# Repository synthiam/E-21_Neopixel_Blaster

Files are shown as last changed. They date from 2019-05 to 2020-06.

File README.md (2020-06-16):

# E-21 Neopixel Blaster

**Project Status:** Ready to manufacture

If you are new to GitHub and would like to create a derivative of this project, please have a look at GitHub instructions to [fork a repo](https://help.github.com/en/articles/fork-a-repo)

## Description

Out of our passion to solve the issue of time waste in the robot creation process, ARC was born. The ARC software platform reduces the time it takes to get from idea to implementation. Since 2011 we have been listening to the challenges robot builders encounter and continue to provide them with an ever expanding toolbox of solutions. Join us on this journey!

We didn't stop at the software, we also made time saving hardware solutions. This Neopixel Blaster reference design is one of them. The Neopixel blaster connects WS2812 Addressable RGB LEDs to ARC. By utilizing ARC, the Neopixel Blaster can create animations and display all kinds of colors with WS2812B LEDs. A unique feature of this board is that it allows any EZ-Builder compatible board to use Neopixel LEDs, no libraries or precision timing required. We want to share these files with you so you can create your own version for your community and customers to enjoy!

**Features:** 
- 8 channels 
- Control up to 80 LEDs per channel
- Each LED can display 1 of 16 million different colors
- Mini programming header
- 5V tolerant I/O pins
- RGB LED status indicator
- ARC skill available
- Voltage requirement: 6-18VDC (7.4V Typical)
- Current draw: WS2812B off - 7mA, WS2812B white - 46mA
- Dimensions: 29.7(W) x 35.7(L) x 11.5(H) (mm)
- Weight: 5g

**Major components:** 
- PIC16F1704-I/ST 8-bit PIC microcontroller (custom firmware provided)
- NCP1117ST50T3GOSCT 5V Linear voltage regulator
- WS2812B Addressable RGB LED

**Manufacturing notes:** 
1. Supplier: programs custom firmware into the PIC16F1704-I/ST at their facility before sending to manufacturer
2. Manufacturer: Single side placement and soldering of SMT components
3. Manufacturer: Single Side soldering of THT components

**Note:** This reference design pairs with either a WS2812B NeoPixel LED or a Blaster Bit from here: https://github.com/synthiam/E-22_Blaster_Bit

## Contents

[**Documentation:**](https://github.com/synthiam/E-21_Neopixel_Blaster/tree/master/E-21%20Documentation) Schematic PDF, Datasheet PDF, BOM, Test Procedures

[**Hardware:**](https://github.com/synthiam/E-21_Neopixel_Blaster/tree/master/E-21%20Hardware) Altium PCB design File, Altium SCH Design File, Gerbers

[**Firmware:**](https://github.com/synthiam/E-21_Neopixel_Blaster/tree/master/E-21%20Firmware) Code, Compiled Hex

*Altium Libraries are also available <a href="https://github.com/synthiam/Synthiam_Altium_Librairies">here</a>*

## Photos

<p align="left">


</p>

## Roll Out Video

This Roll-out Video includes:

1. Feature set 
2. Hook-up guide 
3. Using Synthiam EZ-Builder Software Behavior Control
4. Custom firmware location
5. Schematic overview
6. Bill of Materials (BOM) overview
7. Assembly instructions 

Link: https://youtu.be/iWZ4e5sMYgQ



## ARC Skill

The ARC Neopixel Blaster skill makes it easy to control the Neopixel LEDs. The LED colors can be chained and activated with a simple code segment. 

Link: https://synthiam.com/Software/Manual/Neopixel-Blaster-16172



## Contact

For profit use of these files requires written consent. Contact partners@synthiam.com. For everyone else, party on!

For support check out our Synthiam Community: https://synthiam.com/Community

## License

This project is released under the following licenses:

**Hardware:** Creative Commons Plus Attribution-NonCommercial 4.0 International (CC+ BY-NC 4.0)

**Firmware:** Apache 2.0 + “Commons Clause” License Condition v1.0

Please see [LICENSE.md](https://github.com/synthiam/E-21_Neopixel_Blaster/blob/master/LICENSE.md) for license details.



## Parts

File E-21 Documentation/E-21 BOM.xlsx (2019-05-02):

Qty | Description | Manufacturer Part No. | Alternative | Designator | Custom Information | Link
E-21 Neopixel Blaster
1 | 2 layer, Blue soldermask, White silkscreen, ENIG | Neopixel Blaster Board |  | PCB
1 | MicroChip PIC microcontroller | PIC16F1704-I/ST |  | U1 | Needs custom Firmware programmed into chip | https://www.digikey.ca/products/en?keywords=PIC16F1704-I%2FST
1 | 5V Linear voltage regulator (1A) upto 18V | NCP1117ST50T3GOSCT |  | VR1 |  | https://www.digikey.ca/products/en?keywords=NCP1117ST50T3GOSCT
2 | 0.1uF 16V 0805 Ceramic Capacitor | CL21F104ZBCNNNC | C0805C104K5RAC | C3, C4
2 | 10uF 25V 0805 Ceramic Capacitor | CL21A106KAFN3NE |  | C1, C2
1 | 4.7kohm 0805 Chip resistor | RR1220P-472-D |  | R1
1 | 40-pin White Male 0.1" pitch Header |  |  | P7, P10 | This header needs to be broken down into 2 x 4-pin | https://www.adafruit.com/product/4149
1 | 40-pin Red Male 0.1" pitch Header | FIT0084-R |  | P8, P11 | This header needs to be broken down into 2 x 4-pin | https://www.dfrobot.com/product-650.html#.Ulc-U1CshcZ
1 | 40-pin Black Male 0.1” pitch header | FIT0084-B | 00834 | P9, P12 | This header needs to be broken down into 2 x 4-pin | http://www.4uconnector.com/online/SearchPro.asp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
1 | Addressable RGB LED | WS2812B |  | U2 |  | https://www.alibaba.com/product-detail/SK6812B-WS2812B-5050-RGB-Packing-LED_60329442470.html
1 | 3 position 2.0mm pitch JST-PH header | B3B-PH-K-S(LF)(SN) |  | P2 |  | https://www.digikey.ca/product-detail/en/jst-sales-america-inc/B3B-PH-K-S-LF-SN/455-1705-ND/926612

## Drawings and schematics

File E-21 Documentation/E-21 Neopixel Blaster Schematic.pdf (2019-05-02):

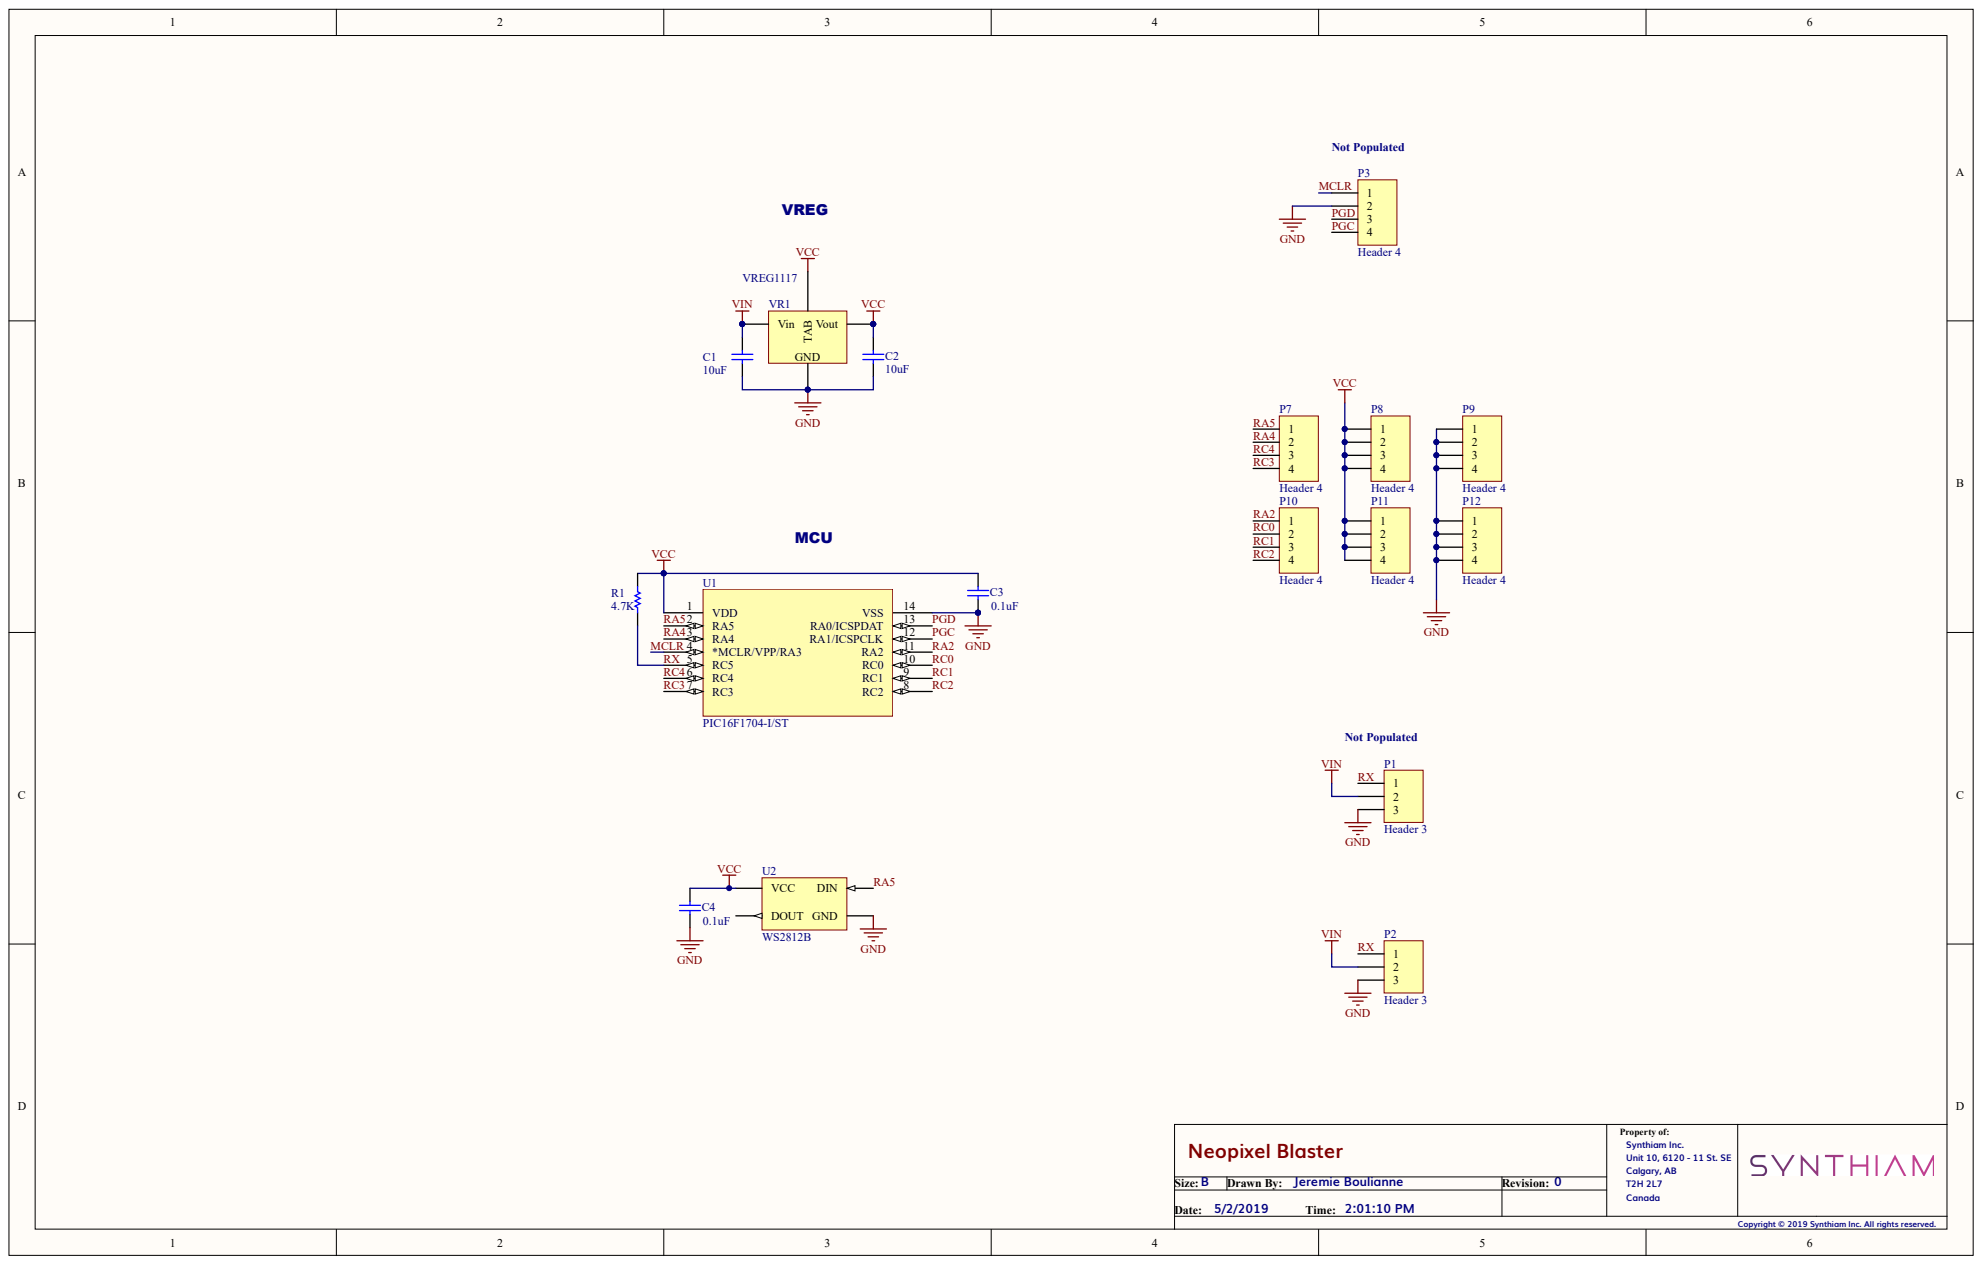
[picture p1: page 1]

Neopixel Blaster | Property of: Synthiam Inc. Unit 10, 6120 - 11 St. SE Calgary, AB T2H 2L7 Canada

B Size: | Jeremie Boulianne Drawn By: | 0 Revision:
5/2/2019 2:01:10 PM Date: Time:

Copyright © 2019 Synthiam Inc. All rights reserved.

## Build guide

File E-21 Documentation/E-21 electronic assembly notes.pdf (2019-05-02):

# Assembly Instructions

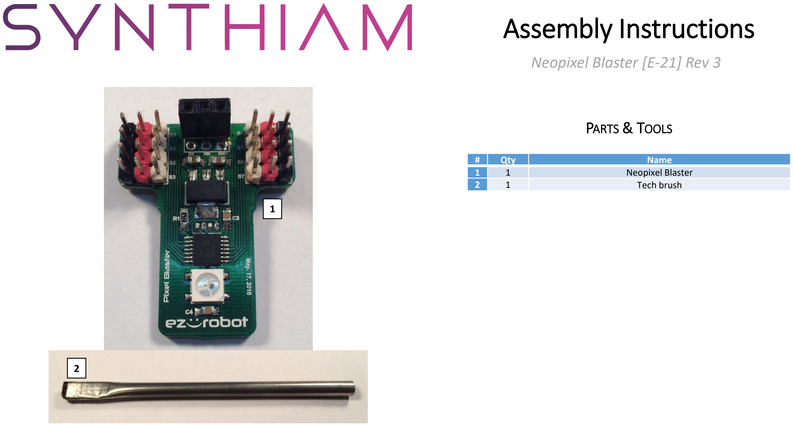
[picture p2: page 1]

# | Qty | Name

1 | 1 | Neopixel Blaster
2 | 1 | Tech brush

Neopixel Blaster [E-21] Rev 3

PARTS & TOOLS

1

2

U1

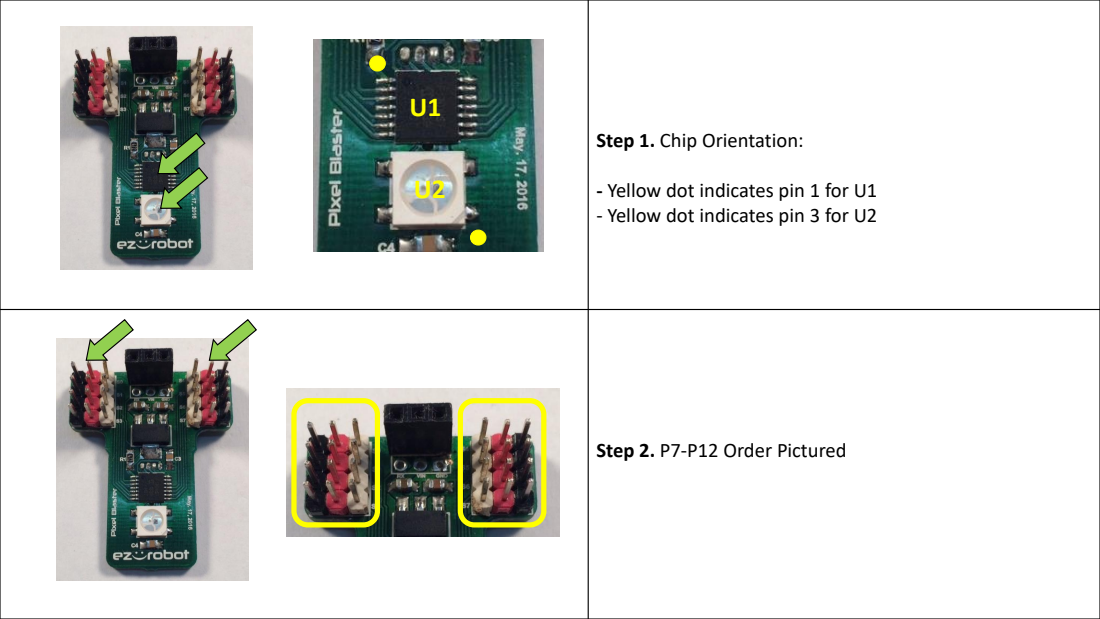
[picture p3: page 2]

Step 1. Chip Orientation:

- Yellow dot indicates pin 1 for U1
- Yellow dot indicates pin 3 for U2

Step 2. P7-P12 Order Pictured

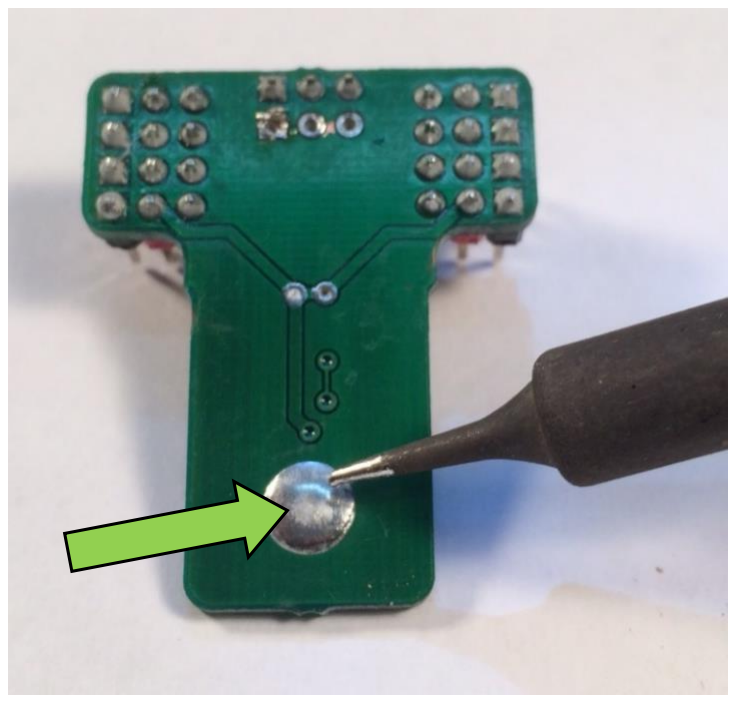
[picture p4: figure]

Step 3. Solder a ~0.020” high circular blob on area pictured

*IMPORTANT*
This is step is imperative for precision fit with ez-clip slots.

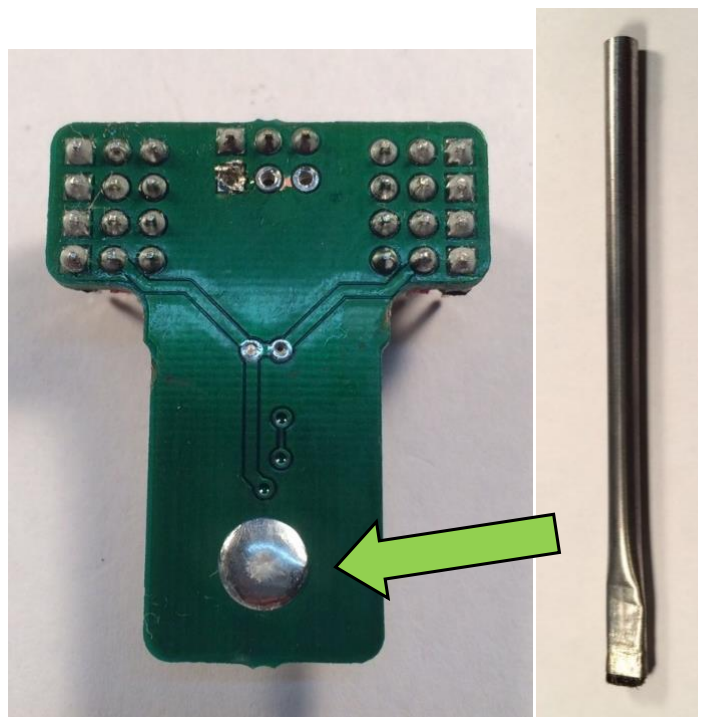
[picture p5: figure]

Step 4. Clean the flux of the PCB with a tech brush

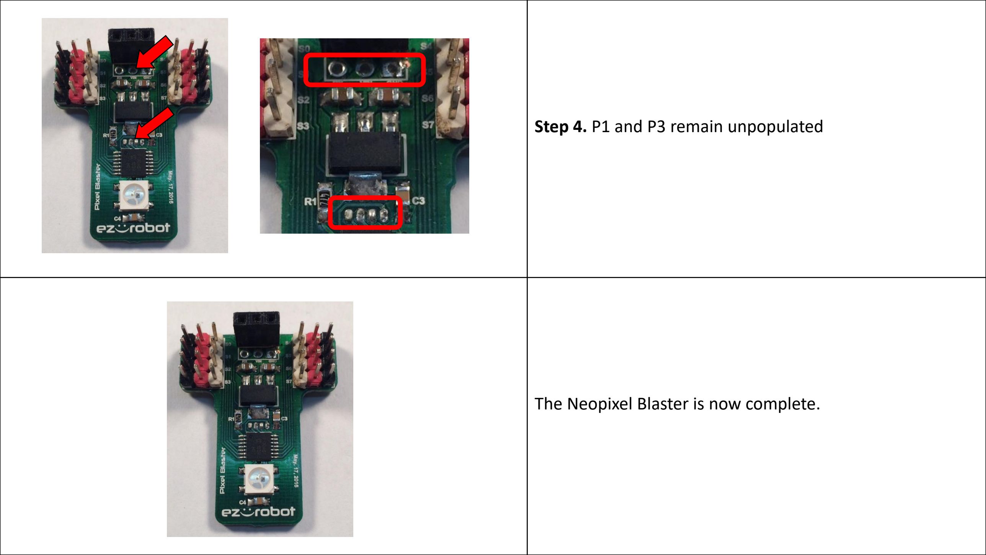
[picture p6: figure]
The Neopixel Blaster is now complete.

Step 4. P1 and P3 remain unpopulatedrush

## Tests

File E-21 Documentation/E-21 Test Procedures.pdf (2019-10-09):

# E-21 Test Procedures

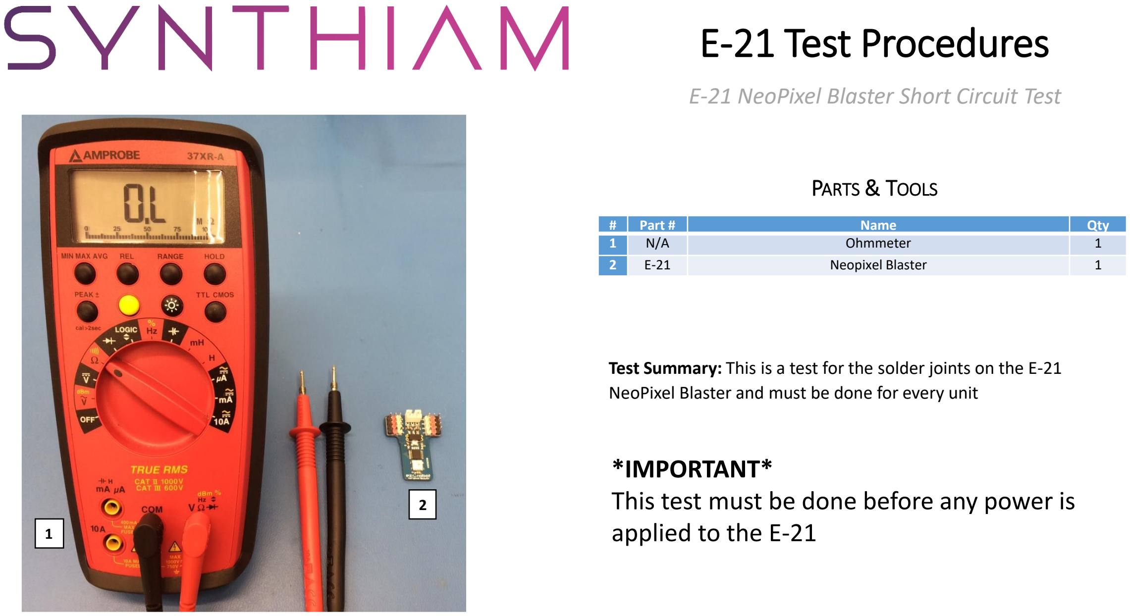
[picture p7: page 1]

# | Part # | Name | Qty

1 | N/A | Ohmmeter | 1
2 | E-21 | Neopixel Blaster | 1

E-21 NeoPixel Blaster Short Circuit Test

PARTS & TOOLS

Test Summary: This is a test for the solder joints on the E-21 NeoPixel Blaster and must be done for every unit

*IMPORTANT*
This test must be done before any power is

### 1 applied to the E-21

2

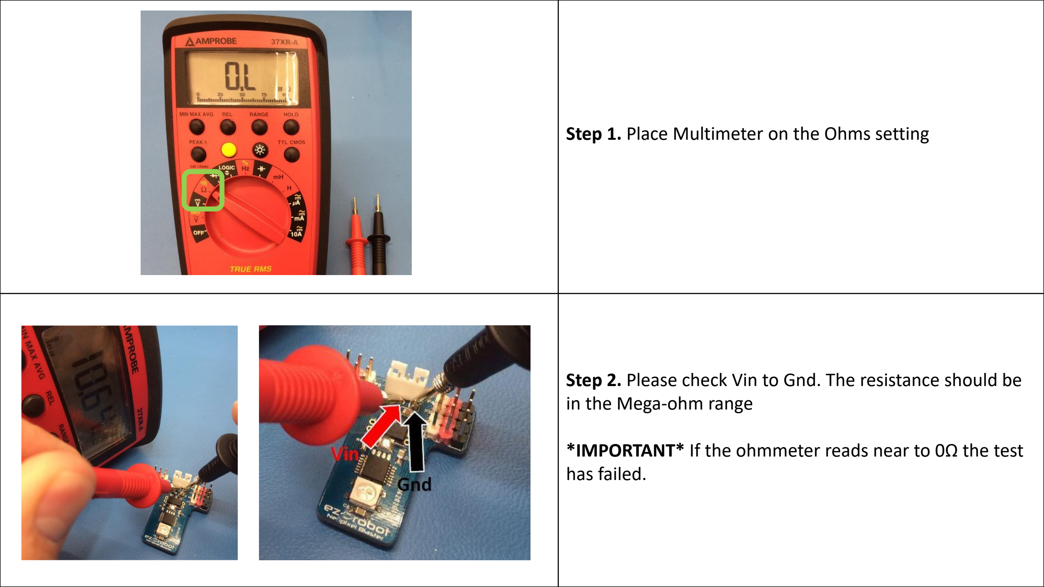
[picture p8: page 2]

Step 1. Place Multimeter on the Ohms setting
Step 2. Please check Vin to Gnd. The resistance should be in the Mega-ohm range

*IMPORTANT* If the ohmmeter reads near to 0Ω the test has failed.

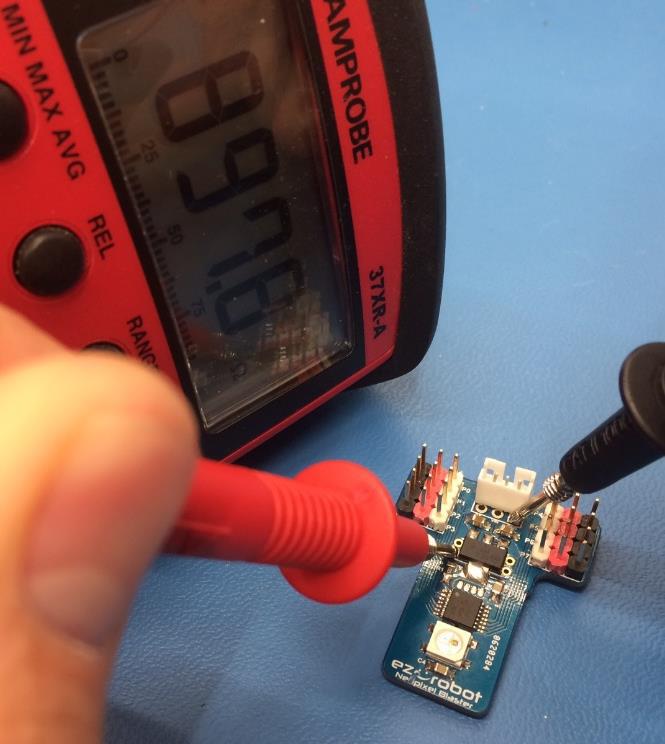
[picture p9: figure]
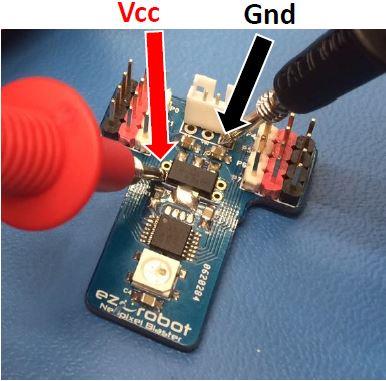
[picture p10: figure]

Step 3. Please check Vcc to Gnd. The resistance should be over 800ohms. The E-21 Short Circuit Test is now complete

*IMPORTANT* If the ohmmeter reads near to 0Ω the test has failed.

# E-21 Test Procedures

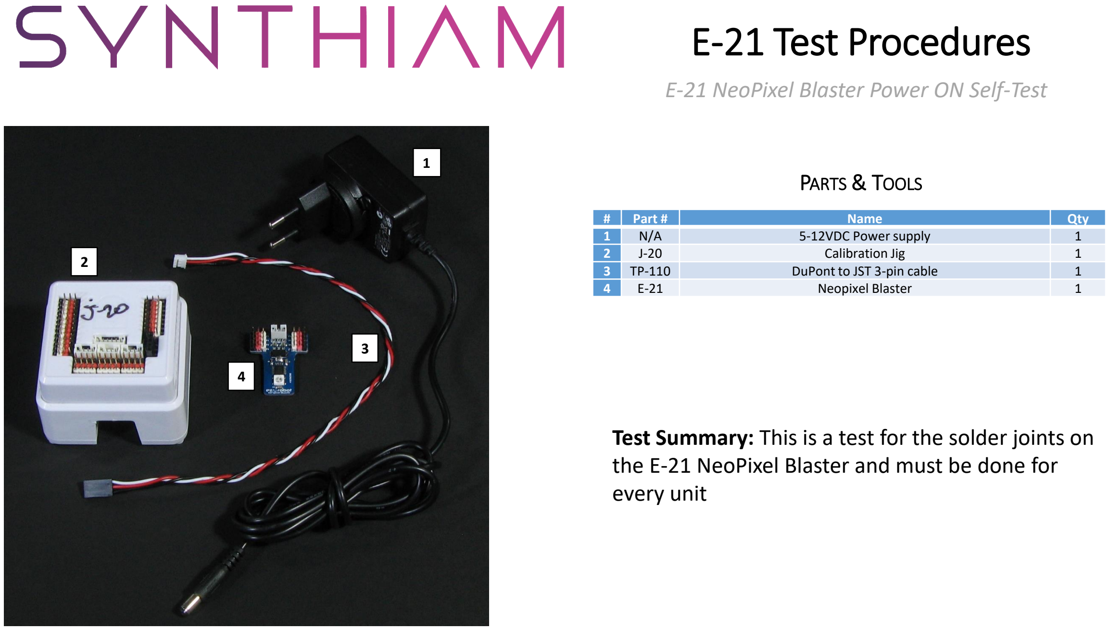
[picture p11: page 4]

# | Part # | Name | Qty

1 | N/A | 5-12VDC Power supply | 1
2 | J-20 | Calibration Jig | 1
3 | TP-110 | DuPont to JST 3-pin cable | 1
4 | E-21 | Neopixel Blaster | 1

E-21 NeoPixel Blaster Power ON Self-Test

PARTS & TOOLS

1

2

3

4

Test Summary: This is a test for the solder joints on the E-21 NeoPixel Blaster and must be done for every unit

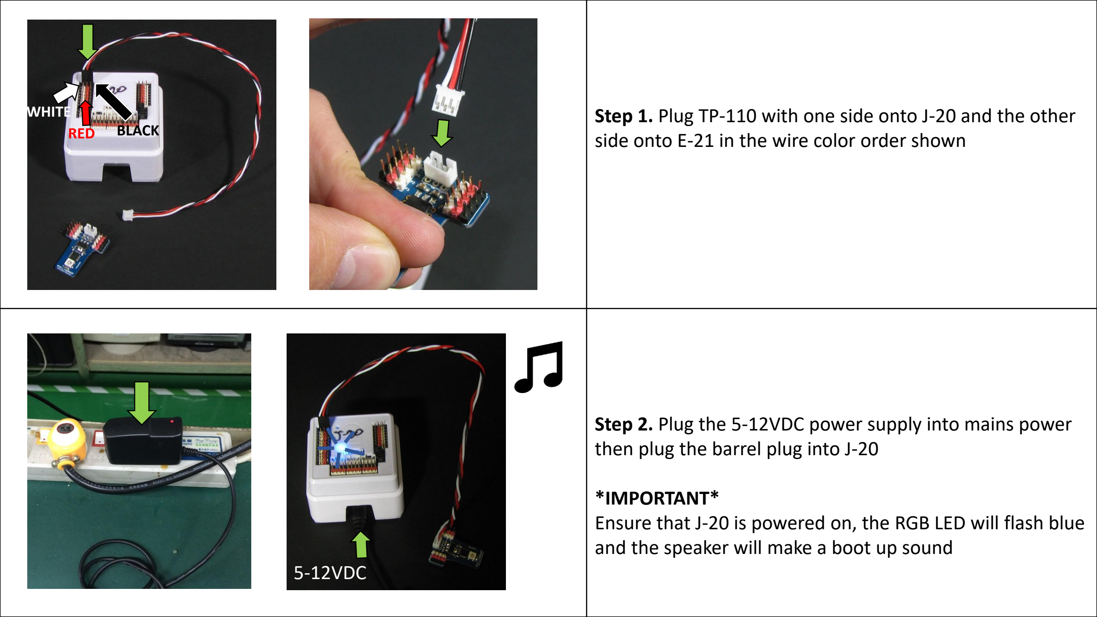
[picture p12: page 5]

Step 1. Plug TP-110 with one side onto J-20 and the other side onto E-21 in the wire color order shown
Step 2. Plug the 5-12VDC power supply into mains power then plug the barrel plug into J-20

*IMPORTANT*
Ensure that J-20 is powered on, the RGB LED will flash blue and the speaker will make a boot up sound

WHITE
RED BLACK

5-12VDC

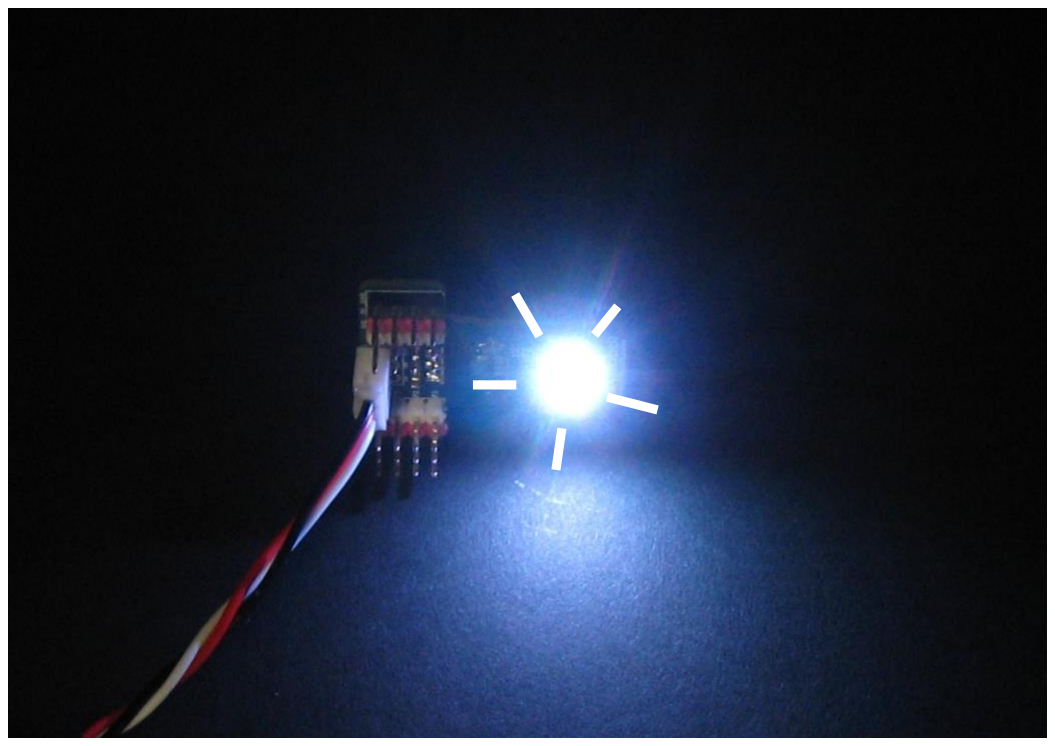
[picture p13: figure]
5-12VDC

Step 3. The LED on E-21 should now flash white very quickly and then turn off

*IMPORTANT* If the LED does not flash E-21 has failed the Power ON test

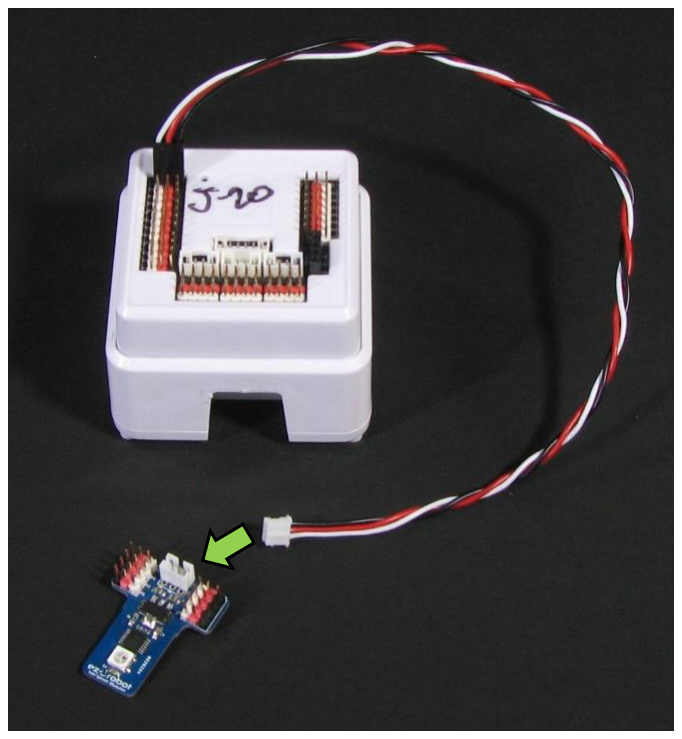
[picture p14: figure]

Step 4. Remove E-21 from TP-110. The E-21 Power ON Self-Test is now complete

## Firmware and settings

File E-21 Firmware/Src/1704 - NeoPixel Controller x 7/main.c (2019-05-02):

#include <main.h>

volatile char _buffer[240];     // This buffer is used to transmit to the neo pixels. support for 80 neopixels per channel
volatile char _outputPort;
volatile char _bufferSize;

volatile char _bufferRecv[240]; // This buffer is used in the receive from the COMM. support for 80 neopixels per channel
volatile char _outputPortRecv;
volatile char _bufferSizeRecv;

volatile char _inputState; // 0 = get port, 1 = number of leds, 2 = data
volatile char _inputPosition;
volatile int1 _startSending;

#INT_RDA
void  RDA_isr(void) {
  
  switch (_inputState) {
  
    case 0:
    
      // get the port
      _outputPortRecv = getc(COMM);
           
      // next read byte is the number of leds
      _inputState = 1;
      
      break;

    case 1:
    
      // get the number of leds
      _bufferSizeRecv = getc(COMM);
            
      // multiply the number of leds by 3 to get the buffer size (for each color of red green blue)
      _bufferSizeRecv += _bufferSizeRecv + _bufferSizeRecv;
              
      // all next bytes are the data
      _inputState = 2;
      
      break;
      
    case 2:

      _bufferRecv[_inputPosition] = getc(COMM);
      
      _inputPosition++;
      
      if (_inputPosition == _bufferSizeRecv)        
        _startSending = true; // tell the main loop to start sending
      
      break;
  }  
}

#inline
void ChangeLED0() {

  for (unsigned int16 p=0; p < _bufferSize; p++) {
  
    char dataByte = _buffer[p];
    
    if (bit_test(dataByte, 7)) {
    
      output_high(pin_a5);
      delay_cycles(DELAY_HIGH_1);
      output_low(pin_a5);
//        delay_cycles(DELAY_LOW_1);
    } else {
    
      output_high(pin_a5);
      delay_cycles(DELAY_HIGH_0);
      output_low(pin_a5);
      delay_cycles(DELAY_LOW_0);
    }             
    
    if (bit_test(dataByte, 6)) {
    
      output_high(pin_a5);
      delay_cycles(DELAY_HIGH_1);
      output_low(pin_a5);
//        delay_cycles(DELAY_LOW_1);
    } else {
    
      output_high(pin_a5);
      delay_cycles(DELAY_HIGH_0);
      output_low(pin_a5);
      delay_cycles(DELAY_LOW_0);
    }             
    
    if (bit_test(dataByte, 5)) {
    
      output_high(pin_a5);
      delay_cycles(DELAY_HIGH_1);
      output_low(pin_a5);
//        delay_cycles(DELAY_LOW_1);
    } else {
    
      output_high(pin_a5);
      delay_cycles(DELAY_HIGH_0);
      output_low(pin_a5);
      delay_cycles(DELAY_LOW_0);
    }             
    
    if (bit_test(dataByte, 4)) {
    
      output_high(pin_a5);
      delay_cycles(DELAY_HIGH_1);
      output_low(pin_a5);
//        delay_cycles(DELAY_LOW_1);
    } else {
    
      output_high(pin_a5);
      delay_cycles(DELAY_HIGH_0);
      output_low(pin_a5);
      delay_cycles(DELAY_LOW_0);
    }             
    
    if (bit_test(dataByte, 3)) {
    
      output_high(pin_a5);
      delay_cycles(DELAY_HIGH_1);
      output_low(pin_a5);
//        delay_cycles(DELAY_LOW_1);
    } else {
    
      output_high(pin_a5);
      delay_cycles(DELAY_HIGH_0);
      output_low(pin_a5);
      delay_cycles(DELAY_LOW_0);
    }             
    
    if (bit_test(dataByte, 2)) {
    
      output_high(pin_a5);
      delay_cycles(DELAY_HIGH_1);
      output_low(pin_a5);
//        delay_cycles(DELAY_LOW_1);
    } else {
    
      output_high(pin_a5);
      delay_cycles(DELAY_HIGH_0);
      output_low(pin_a5);
      delay_cycles(DELAY_LOW_0);
    }             
    
    if (bit_test(dataByte, 1)) {
    
      output_high(pin_a5);
      delay_cycles(DELAY_HIGH_1);
      output_low(pin_a5);
//        delay_cycles(DELAY_LOW_1);
    } else {
    
      output_high(pin_a5);
      delay_cycles(DELAY_HIGH_0);
      output_low(pin_a5);
      delay_cycles(DELAY_LOW_0);
    }             

    if (bit_test(dataByte, 0)) {
    
      output_high(pin_a5);
      delay_cycles(DELAY_HIGH_1);
      output_low(pin_a5);
//        delay_cycles(DELAY_LOW_1);
    } else {
    
      output_high(pin_a5);
      delay_cycles(DELAY_HIGH_0);
      output_low(pin_a5);
      delay_cycles(DELAY_LOW_0);
    }             
  }
}

#inline
void ChangeLED1() {

  for (unsigned int16 p=0; p < _bufferSize; p++) {
  
    char dataByte = _buffer[p];
    
    if (bit_test(dataByte, 7)) {
    
      output_high(pin_a4);
      delay_cycles(DELAY_HIGH_1);
      output_low(pin_a4);
//        delay_cycles(DELAY_LOW_1);
    } else {
    
      output_high(pin_a4);
      delay_cycles(DELAY_HIGH_0);
      output_low(pin_a4);
      delay_cycles(DELAY_LOW_0);
    }             
    
    if (bit_test(dataByte, 6)) {
    
      output_high(pin_a4);
      delay_cycles(DELAY_HIGH_1);
      output_low(pin_a4);
//        delay_cycles(DELAY_LOW_1);
    } else {
    
      output_high(pin_a4);
      delay_cycles(DELAY_HIGH_0);
      output_low(pin_a4);
      delay_cycles(DELAY_LOW_0);
    }             
    
    if (bit_test(dataByte, 5)) {
    
      output_high(pin_a4);
      delay_cycles(DELAY_HIGH_1);
      output_low(pin_a4);
//        delay_cycles(DELAY_LOW_1);
    } else {
    
      output_high(pin_a4);
      delay_cycles(DELAY_HIGH_0);
      output_low(pin_a4);
      delay_cycles(DELAY_LOW_0);
    }             
    
    if (bit_test(dataByte, 4)) {
    
      output_high(pin_a4);
      delay_cycles(DELAY_HIGH_1);
      output_low(pin_a4);
//        delay_cycles(DELAY_LOW_1);
    } else {
    
      output_high(pin_a4);
      delay_cycles(DELAY_HIGH_0);
      output_low(pin_a4);
      delay_cycles(DELAY_LOW_0);
    }             
    
    if (bit_test(dataByte, 3)) {
    
      output_high(pin_a4);
      delay_cycles(DELAY_HIGH_1);
      output_low(pin_a4);
//        delay_cycles(DELAY_LOW_1);
    } else {
    
      output_high(pin_a4);
      delay_cycles(DELAY_HIGH_0);
      output_low(pin_a4);
      delay_cycles(DELAY_LOW_0);
    }             
    
    if (bit_test(dataByte, 2)) {
    
      output_high(pin_a4);
      delay_cycles(DELAY_HIGH_1);
      output_low(pin_a4);
//        delay_cycles(DELAY_LOW_1);
    } else {
    
      output_high(pin_a4);
      delay_cycles(DELAY_HIGH_0);
      output_low(pin_a4);
      delay_cycles(DELAY_LOW_0);
    }             
    
    if (bit_test(dataByte, 1)) {
    
      output_high(pin_a4);
      delay_cycles(DELAY_HIGH_1);
      output_low(pin_a4);
//        delay_cycles(DELAY_LOW_1);
    } else {
    
      output_high(pin_a4);
      delay_cycles(DELAY_HIGH_0);
      output_low(pin_a4);
      delay_cycles(DELAY_LOW_0);
    }             

    if (bit_test(dataByte, 0)) {
    
      output_high(pin_a4);
      delay_cycles(DELAY_HIGH_1);
      output_low(pin_a4);
//        delay_cycles(DELAY_LOW_1);
    } else {
    
      output_high(pin_a4);
      delay_cycles(DELAY_HIGH_0);
      output_low(pin_a4);
      delay_cycles(DELAY_LOW_0);
    }             
  }
}

#inline
void ChangeLED2() {

  for (unsigned int16 p=0; p < _bufferSize; p++) {
  
    char dataByte = _buffer[p];
    
    if (bit_test(dataByte, 7)) {
    
      output_high(pin_c4);
      delay_cycles(DELAY_HIGH_1);
      output_low(pin_c4);
//        delay_cycles(DELAY_LOW_1);
    } else {
    
      output_high(pin_c4);
      delay_cycles(DELAY_HIGH_0);
      output_low(pin_c4);
      delay_cycles(DELAY_LOW_0);
    }             
    
    if (bit_test(dataByte, 6)) {
    
      output_high(pin_c4);
      delay_cycles(DELAY_HIGH_1);
      output_low(pin_c4);
//        delay_cycles(DELAY_LOW_1);
    } else {
    
      output_high(pin_c4);
      delay_cycles(DELAY_HIGH_0);
      output_low(pin_c4);
      delay_cycles(DELAY_LOW_0);
    }             
    
    if (bit_test(dataByte, 5)) {
    
      output_high(pin_c4);
      delay_cycles(DELAY_HIGH_1);
      output_low(pin_c4);
//        delay_cycles(DELAY_LOW_1);
    } else {
    
      output_high(pin_c4);
      delay_cycles(DELAY_HIGH_0);
      output_low(pin_c4);
      delay_cycles(DELAY_LOW_0);
    }             
    
    if (bit_test(dataByte, 4)) {
    
      output_high(pin_c4);
      delay_cycles(DELAY_HIGH_1);
      output_low(pin_c4);
//        delay_cycles(DELAY_LOW_1);
    } else {
    
      output_high(pin_c4);
      delay_cycles(DELAY_HIGH_0);
      output_low(pin_c4);
      delay_cycles(DELAY_LOW_0);
    }             
    
    if (bit_test(dataByte, 3)) {
    
      output_high(pin_c4);
      delay_cycles(DELAY_HIGH_1);
      output_low(pin_c4);
//        delay_cycles(DELAY_LOW_1);
    } else {
    
      output_high(pin_c4);
      delay_cycles(DELAY_HIGH_0);
      output_low(pin_c4);
      delay_cycles(DELAY_LOW_0);
    }             
    
    if (bit_test(dataByte, 2)) {
    
      output_high(pin_c4);
      delay_cycles(DELAY_HIGH_1);
      output_low(pin_c4);
//        delay_cycles(DELAY_LOW_1);
    } else {
    
      output_high(pin_c4);
      delay_cycles(DELAY_HIGH_0);
      output_low(pin_c4);
      delay_cycles(DELAY_LOW_0);
    }             
    
    if (bit_test(dataByte, 1)) {
    
      output_high(pin_c4);
      delay_cycles(DELAY_HIGH_1);
      output_low(pin_c4);
//        delay_cycles(DELAY_LOW_1);
    } else {
    
      output_high(pin_c4);
      delay_cycles(DELAY_HIGH_0);
      output_low(pin_c4);
      delay_cycles(DELAY_LOW_0);
    }             

    if (bit_test(dataByte, 0)) {
    
      output_high(pin_c4);
      delay_cycles(DELAY_HIGH_1);
      output_low(pin_c4);
//        delay_cycles(DELAY_LOW_1);
    } else {
    
      output_high(pin_c4);
      delay_cycles(DELAY_HIGH_0);
      output_low(pin_c4);
      delay_cycles(DELAY_LOW_0);
    }             
  }
}

#inline
void ChangeLED3() {

  for (unsigned int16 p=0; p < _bufferSize; p++) {
  
    char dataByte = _buffer[p];
    
    if (bit_test(dataByte, 7)) {
    
      output_high(pin_c3);
      delay_cycles(DELAY_HIGH_1);
      output_low(pin_c3);
//        delay_cycles(DELAY_LOW_1);
    } else {
    
      output_high(pin_c3);
      delay_cycles(DELAY_HIGH_0);
      output_low(pin_c3);
      delay_cycles(DELAY_LOW_0);
    }             
    
    if (bit_test(dataByte, 6)) {
    
      output_high(pin_c3);
      delay_cycles(DELAY_HIGH_1);
      output_low(pin_c3);
//        delay_cycles(DELAY_LOW_1);
    } else {
    
      output_high(pin_c3);
      delay_cycles(DELAY_HIGH_0);
      output_low(pin_c3);
      delay_cycles(DELAY_LOW_0);
    }             
    
    if (bit_test(dataByte, 5)) {
    
      output_high(pin_c3);
      delay_cycles(DELAY_HIGH_1);
      output_low(pin_c3);
//        delay_cycles(DELAY_LOW_1);
    } else {
    
      output_high(pin_c3);
      delay_cycles(DELAY_HIGH_0);
      output_low(pin_c3);
      delay_cycles(DELAY_LOW_0);
    }             
    
    if (bit_test(dataByte, 4)) {
    
      output_high(pin_c3);
      delay_cycles(DELAY_HIGH_1);
      output_low(pin_c3);
//        delay_cycles(DELAY_LOW_1);
    } else {
    
      output_high(pin_c3);
      delay_cycles(DELAY_HIGH_0);
      output_low(pin_c3);
      delay_cycles(DELAY_LOW_0);
    }             
    
    if (bit_test(dataByte, 3)) {
    
      output_high(pin_c3);
      delay_cycles(DELAY_HIGH_1);
      output_low(pin_c3);
//        delay_cycles(DELAY_LOW_1);
    } else {
    
      output_high(pin_c3);
      delay_cycles(DELAY_HIGH_0);
      output_low(pin_c3);
      delay_cycles(DELAY_LOW_0);
    }             
    
    if (bit_test(dataByte, 2)) {
    
      output_high(pin_c3);
      delay_cycles(DELAY_HIGH_1);
      output_low(pin_c3);
//        delay_cycles(DELAY_LOW_1);
    } else {
    
      output_high(pin_c3);
      delay_cycles(DELAY_HIGH_0);
      output_low(pin_c3);
      delay_cycles(DELAY_LOW_0);
    }             
    
    if (bit_test(dataByte, 1)) {
    
      output_high(pin_c3);
      delay_cycles(DELAY_HIGH_1);
      output_low(pin_c3);
//        delay_cycles(DELAY_LOW_1);
    } else {
    
      output_high(pin_c3);
      delay_cycles(DELAY_HIGH_0);
      output_low(pin_c3);
      delay_cycles(DELAY_LOW_0);
    }             

    if (bit_test(dataByte, 0)) {
    
      output_high(pin_c3);
      delay_cycles(DELAY_HIGH_1);
      output_low(pin_c3);
//        delay_cycles(DELAY_LOW_1);
    } else {
    
      output_high(pin_c3);
      delay_cycles(DELAY_HIGH_0);
      output_low(pin_c3);
      delay_cycles(DELAY_LOW_0);
    }             
  }
}

#inline
void ChangeLED4() {

  for (unsigned int16 p=0; p < _bufferSize; p++) {
  
    char dataByte = _buffer[p];
    
    if (bit_test(dataByte, 7)) {
    
      output_high(pin_a2);
      delay_cycles(DELAY_HIGH_1);
      output_low(pin_a2);
//        delay_cycles(DELAY_LOW_1);
    } else {
    
      output_high(pin_a2);
      delay_cycles(DELAY_HIGH_0);
      output_low(pin_a2);
      delay_cycles(DELAY_LOW_0);
    }             
    
    if (bit_test(dataByte, 6)) {
    
      output_high(pin_a2);
      delay_cycles(DELAY_HIGH_1);
      output_low(pin_a2);
//        delay_cycles(DELAY_LOW_1);
    } else {
    
      output_high(pin_a2);
      delay_cycles(DELAY_HIGH_0);
      output_low(pin_a2);
      delay_cycles(DELAY_LOW_0);
    }             
    
    if (bit_test(dataByte, 5)) {
    
      output_high(pin_a2);
      delay_cycles(DELAY_HIGH_1);
      output_low(pin_a2);
//        delay_cycles(DELAY_LOW_1);
    } else {
    
      output_high(pin_a2);
      delay_cycles(DELAY_HIGH_0);
      output_low(pin_a2);
      delay_cycles(DELAY_LOW_0);
    }             
    
    if (bit_test(dataByte, 4)) {
    
      output_high(pin_a2);
      delay_cycles(DELAY_HIGH_1);
      output_low(pin_a2);
//        delay_cycles(DELAY_LOW_1);
    } else {
    
      output_high(pin_a2);
      delay_cycles(DELAY_HIGH_0);
      output_low(pin_a2);
      delay_cycles(DELAY_LOW_0);
    }             
    
    if (bit_test(dataByte, 3)) {
    
      output_high(pin_a2);
      delay_cycles(DELAY_HIGH_1);
      output_low(pin_a2);
//        delay_cycles(DELAY_LOW_1);
    } else {
    
      output_high(pin_a2);
      delay_cycles(DELAY_HIGH_0);
      output_low(pin_a2);
      delay_cycles(DELAY_LOW_0);
    }             
    
    if (bit_test(dataByte, 2)) {
    
      output_high(pin_a2);
      delay_cycles(DELAY_HIGH_1);
      output_low(pin_a2);
//        delay_cycles(DELAY_LOW_1);
    } else {
    
      output_high(pin_a2);
      delay_cycles(DELAY_HIGH_0);
      output_low(pin_a2);
      delay_cycles(DELAY_LOW_0);
    }             
    
    if (bit_test(dataByte, 1)) {
    
      output_high(pin_a2);
      delay_cycles(DELAY_HIGH_1);
      output_low(pin_a2);
//        delay_cycles(DELAY_LOW_1);
    } else {
    
      output_high(pin_a2);
      delay_cycles(DELAY_HIGH_0);
      output_low(pin_a2);
      delay_cycles(DELAY_LOW_0);
    }             

    if (bit_test(dataByte, 0)) {
    
      output_high(pin_a2);
      delay_cycles(DELAY_HIGH_1);
      output_low(pin_a2);
//        delay_cycles(DELAY_LOW_1);
    } else {
    
      output_high(pin_a2);
      delay_cycles(DELAY_HIGH_0);
      output_low(pin_a2);
      delay_cycles(DELAY_LOW_0);
    }             
  }
}

#inline
void ChangeLED5() {

  for (unsigned int16 p=0; p < _bufferSize; p++) {
  
    char dataByte = _buffer[p];
    
    if (bit_test(dataByte, 7)) {
    
      output_high(pin_c0);
      delay_cycles(DELAY_HIGH_1);
      output_low(pin_c0);
//        delay_cycles(DELAY_LOW_1);
    } else {
    
      output_high(pin_c0);
      delay_cycles(DELAY_HIGH_0);
      output_low(pin_c0);
      delay_cycles(DELAY_LOW_0);
    }             
    
    if (bit_test(dataByte, 6)) {
    
      output_high(pin_c0);
      delay_cycles(DELAY_HIGH_1);
      output_low(pin_c0);
//        delay_cycles(DELAY_LOW_1);
    } else {
    
      output_high(pin_c0);
      delay_cycles(DELAY_HIGH_0);
      output_low(pin_c0);
      delay_cycles(DELAY_LOW_0);
    }             
    
    if (bit_test(dataByte, 5)) {
    
      output_high(pin_c0);
      delay_cycles(DELAY_HIGH_1);
      output_low(pin_c0);
//        delay_cycles(DELAY_LOW_1);
    } else {
    
      output_high(pin_c0);
      delay_cycles(DELAY_HIGH_0);
      output_low(pin_c0);
      delay_cycles(DELAY_LOW_0);
    }             
    
    if (bit_test(dataByte, 4)) {
    
      output_high(pin_c0);
      delay_cycles(DELAY_HIGH_1);
      output_low(pin_c0);
//        delay_cycles(DELAY_LOW_1);
    } else {
    
      output_high(pin_c0);
      delay_cycles(DELAY_HIGH_0);
      output_low(pin_c0);
      delay_cycles(DELAY_LOW_0);
    }             
    
    if (bit_test(dataByte, 3)) {
    
      output_high(pin_c0);
      delay_cycles(DELAY_HIGH_1);
      output_low(pin_c0);
//        delay_cycles(DELAY_LOW_1);
    } else {
    
      output_high(pin_c0);
      delay_cycles(DELAY_HIGH_0);
      output_low(pin_c0);
      delay_cycles(DELAY_LOW_0);
    }             
    
    if (bit_test(dataByte, 2)) {
    
      output_high(pin_c0);
      delay_cycles(DELAY_HIGH_1);
      output_low(pin_c0);
//        delay_cycles(DELAY_LOW_1);
    } else {
    
      output_high(pin_c0);
      delay_cycles(DELAY_HIGH_0);
      output_low(pin_c0);
      delay_cycles(DELAY_LOW_0);
    }             
    
    if (bit_test(dataByte, 1)) {
    
      output_high(pin_c0);
      delay_cycles(DELAY_HIGH_1);
      output_low(pin_c0);
//        delay_cycles(DELAY_LOW_1);
    } else {
    
      output_high(pin_c0);
      delay_cycles(DELAY_HIGH_0);
      output_low(pin_c0);
      delay_cycles(DELAY_LOW_0);
    }             

    if (bit_test(dataByte, 0)) {
    
      output_high(pin_c0);
      delay_cycles(DELAY_HIGH_1);
      output_low(pin_c0);
//        delay_cycles(DELAY_LOW_1);
    } else {
    
      output_high(pin_c0);
      delay_cycles(DELAY_HIGH_0);
      output_low(pin_c0);
      delay_cycles(DELAY_LOW_0);
    }             
  }
}

#inline
void ChangeLED6() {

  for (unsigned int16 p=0; p < _bufferSize; p++) {
  
    char dataByte = _buffer[p];
    
    if (bit_test(dataByte, 7)) {
    
      output_high(pin_c1);
      delay_cycles(DELAY_HIGH_1);
      output_low(pin_c1);
//        delay_cycles(DELAY_LOW_1);
    } else {
    
      output_high(pin_c1);
      delay_cycles(DELAY_HIGH_0);
      output_low(pin_c1);
      delay_cycles(DELAY_LOW_0);
    }             
    
    if (bit_test(dataByte, 6)) {
    
      output_high(pin_c1);
      delay_cycles(DELAY_HIGH_1);
      output_low(pin_c1);
//        delay_cycles(DELAY_LOW_1);
    } else {
    
      output_high(pin_c1);
      delay_cycles(DELAY_HIGH_0);
      output_low(pin_c1);
      delay_cycles(DELAY_LOW_0);
    }             
    
    if (bit_test(dataByte, 5)) {
    
      output_high(pin_c1);
      delay_cycles(DELAY_HIGH_1);
      output_low(pin_c1);
//        delay_cycles(DELAY_LOW_1);
    } else {
    
      output_high(pin_c1);
      delay_cycles(DELAY_HIGH_0);
      output_low(pin_c1);
      delay_cycles(DELAY_LOW_0);
    }             
    
    if (bit_test(dataByte, 4)) {
    
      output_high(pin_c1);
      delay_cycles(DELAY_HIGH_1);
      output_low(pin_c1);
//        delay_cycles(DELAY_LOW_1);
    } else {
    
      output_high(pin_c1);
      delay_cycles(DELAY_HIGH_0);
      output_low(pin_c1);
      delay_cycles(DELAY_LOW_0);
    }             
    
    if (bit_test(dataByte, 3)) {
    
      output_high(pin_c1);
      delay_cycles(DELAY_HIGH_1);
      output_low(pin_c1);
//        delay_cycles(DELAY_LOW_1);
    } else {
    
      output_high(pin_c1);
      delay_cycles(DELAY_HIGH_0);
      output_low(pin_c1);
      delay_cycles(DELAY_LOW_0);
    }             
    
    if (bit_test(dataByte, 2)) {
    
      output_high(pin_c1);
      delay_cycles(DELAY_HIGH_1);
      output_low(pin_c1);
//        delay_cycles(DELAY_LOW_1);
    } else {
    
      output_high(pin_c1);
      delay_cycles(DELAY_HIGH_0);
      output_low(pin_c1);
      delay_cycles(DELAY_LOW_0);
    }             
    
    if (bit_test(dataByte, 1)) {
    
      output_high(pin_c1);
      delay_cycles(DELAY_HIGH_1);
      output_low(pin_c1);
//        delay_cycles(DELAY_LOW_1);
    } else {
    
      output_high(pin_c1);
      delay_cycles(DELAY_HIGH_0);
      output_low(pin_c1);
      delay_cycles(DELAY_LOW_0);
    }             

    if (bit_test(dataByte, 0)) {
    
      output_high(pin_c1);
      delay_cycles(DELAY_HIGH_1);
      output_low(pin_c1);
//        delay_cycles(DELAY_LOW_1);
    } else {
    
      output_high(pin_c1);
      delay_cycles(DELAY_HIGH_0);
      output_low(pin_c1);
      delay_cycles(DELAY_LOW_0);
    }             
  }
}
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
void main() {

  enable_interrupts(INT_RDA);
  enable_interrupts(GLOBAL);

  // initialize the i/o for the led communications
  output_drive(pin_a5);
  output_drive(pin_a4);
  output_drive(pin_c4);
  output_drive(pin_c3);
  output_drive(pin_a2);
  output_drive(pin_c0);
  output_drive(pin_c1);
  output_drive(pin_c2);
  
  // 0 means waiting for the port on next receive byte
  _inputState = 0;
  
  // reset to the beginning of the buffer for populating
  _inputPosition = 0;

  // do not send when we begin
  _startSending = false;

  while (true) {

    while (!_startSending);

    // 0 means waiting for the port
    _inputState = 0;
    
    // 0 is the first position of the buffer
    _inputPosition = 0;

    // reset the send status to not send
    _startSending = false;

    // copy the data from the receive buffer to the transmit buffer
    for (char tr = 0; tr < _bufferSizeRecv; tr++)
      _buffer[tr] = _bufferRecv[tr];

    _bufferSize = _bufferSizeRecv;
    _outputPort = _outputPortRecv;
 
    switch (_outputPort) {
    
      case 0:
        ChangeLED0();
        break;
      case 1:
        ChangeLED1();
        break;
      case 2:
        ChangeLED2();
        break;
      case 3:
        ChangeLED3();
        break;
      case 4:
        ChangeLED4();
        break;
      case 5:
        ChangeLED5();
        break;
      case 6:
        ChangeLED6();
        break;
      case 7:
        ChangeLED7();
        break;
    }        
  }
}

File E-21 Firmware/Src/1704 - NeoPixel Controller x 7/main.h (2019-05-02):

#include <16F1704.h>
#device ADC=16

#FUSES NOWDT                   //No Watch Dog Timer
#FUSES PROTECT                 //Code protected from reads
#FUSES NOBROWNOUT              //No brownout reset
#FUSES NOLVP                   //No low voltage prgming, B3(PIC16) or B5(PIC18) used for I/O

#use delay(internal=32MHz)

#use FAST_IO(ALL)

#pin_select rx1=pin_C5
#pin_select tx1=pin_C0

#use rs232(baud=57600, parity=N, xmit=pin_C0, rcv=pin_C5, bits=8, stream=COMM, ERRORS)

#define DELAY_HIGH_0 2
#define DELAY_LOW_0 2

#define DELAY_HIGH_1 6
#define DELAY_LOW_1 1
